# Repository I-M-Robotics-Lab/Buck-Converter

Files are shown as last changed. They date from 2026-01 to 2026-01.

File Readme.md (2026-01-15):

# A Simple Buck Converter Unit with ME3121

VIN Input: 5-40V

Output: 5V 1A; 3.3V 500mA

Dimension: 22 x 17 mm

This is a very compact Buck Converter Unit that turns a wide range of input voltage into the common 5V and 3.3V. It is cheap and have better performance than LM2596.

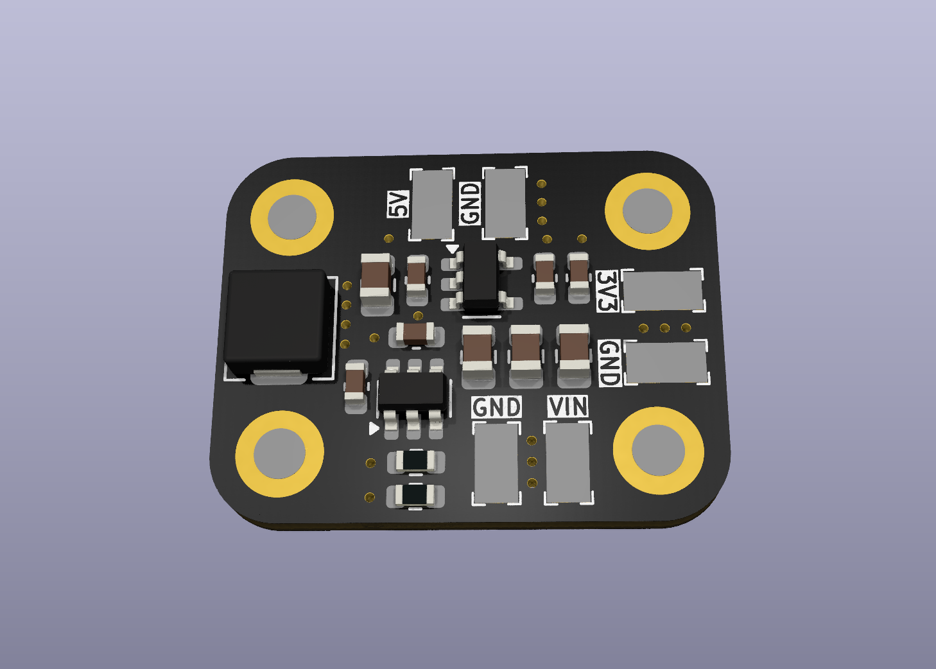
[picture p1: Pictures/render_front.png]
Rendered
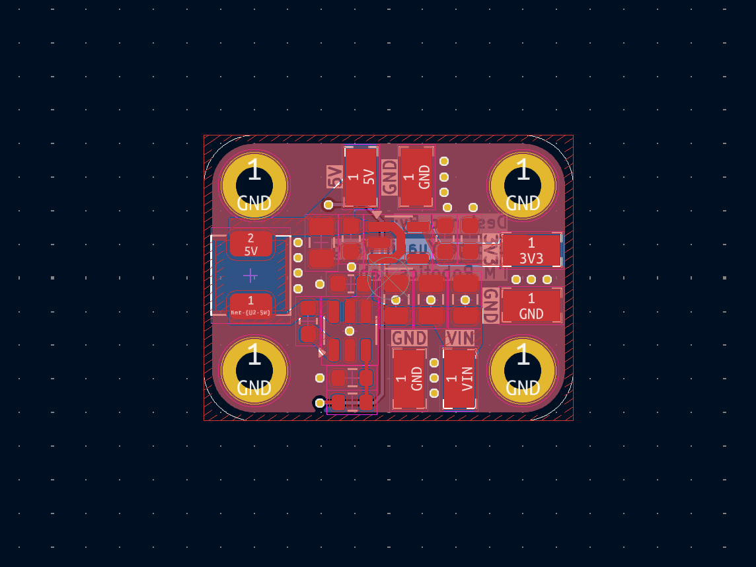
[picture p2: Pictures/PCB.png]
|  |  |
|---|---|

## Schematics

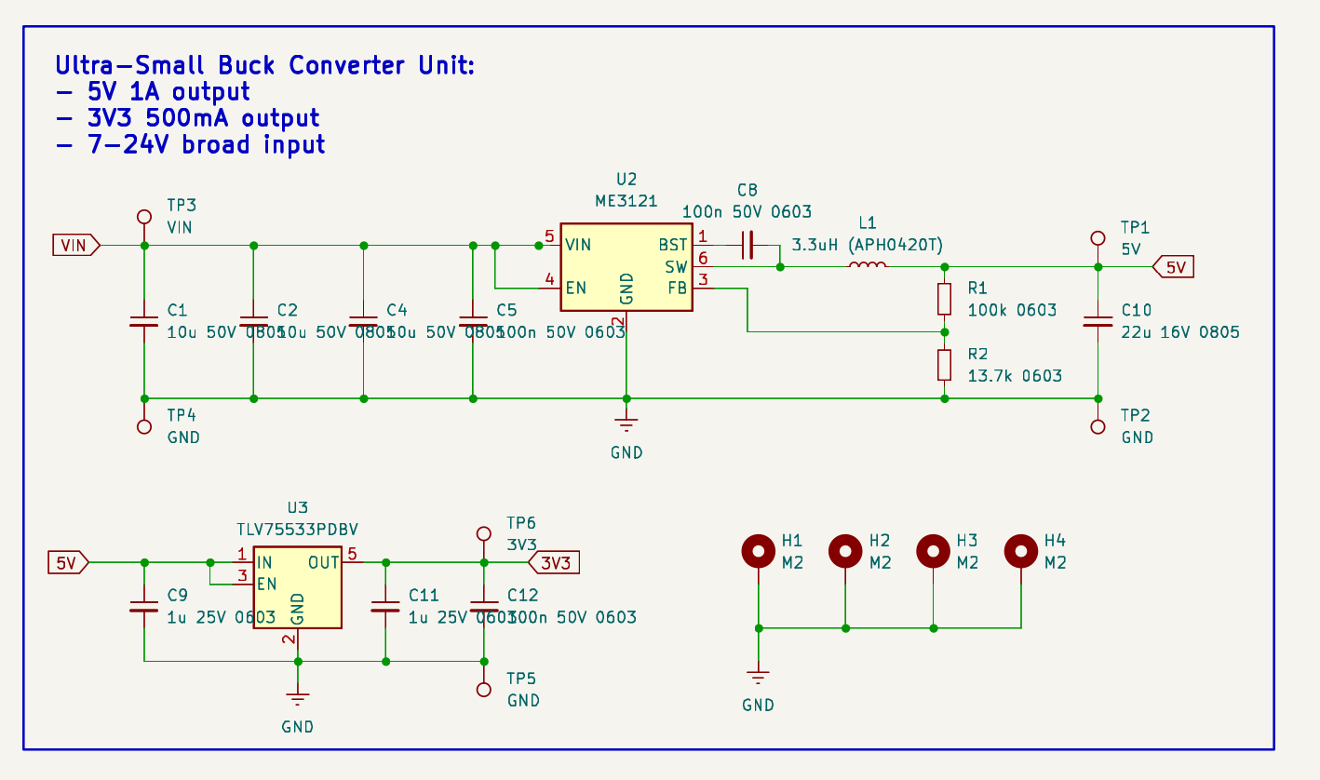
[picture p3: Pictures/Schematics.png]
Schematics


## Order / Manufacturing

Download the `Gerber.zip` file from release and submit it to [JLCPCB](https://cart.jlcpcb.com/quote?spm=jlcpcb.Public.2006), leave everything set as default. 

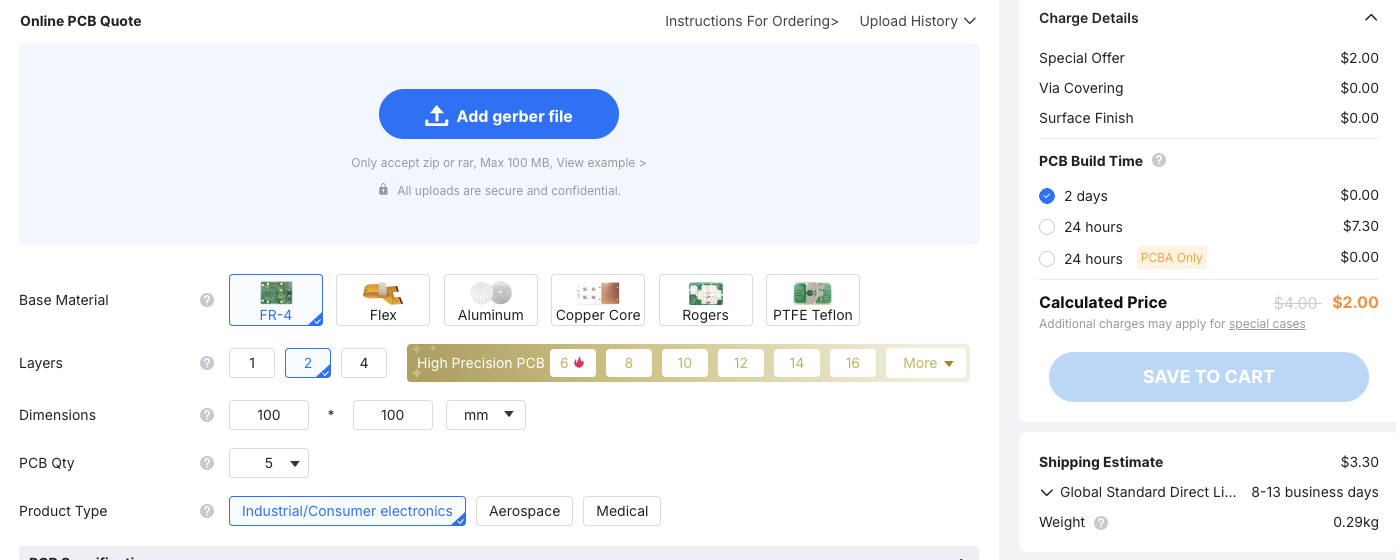
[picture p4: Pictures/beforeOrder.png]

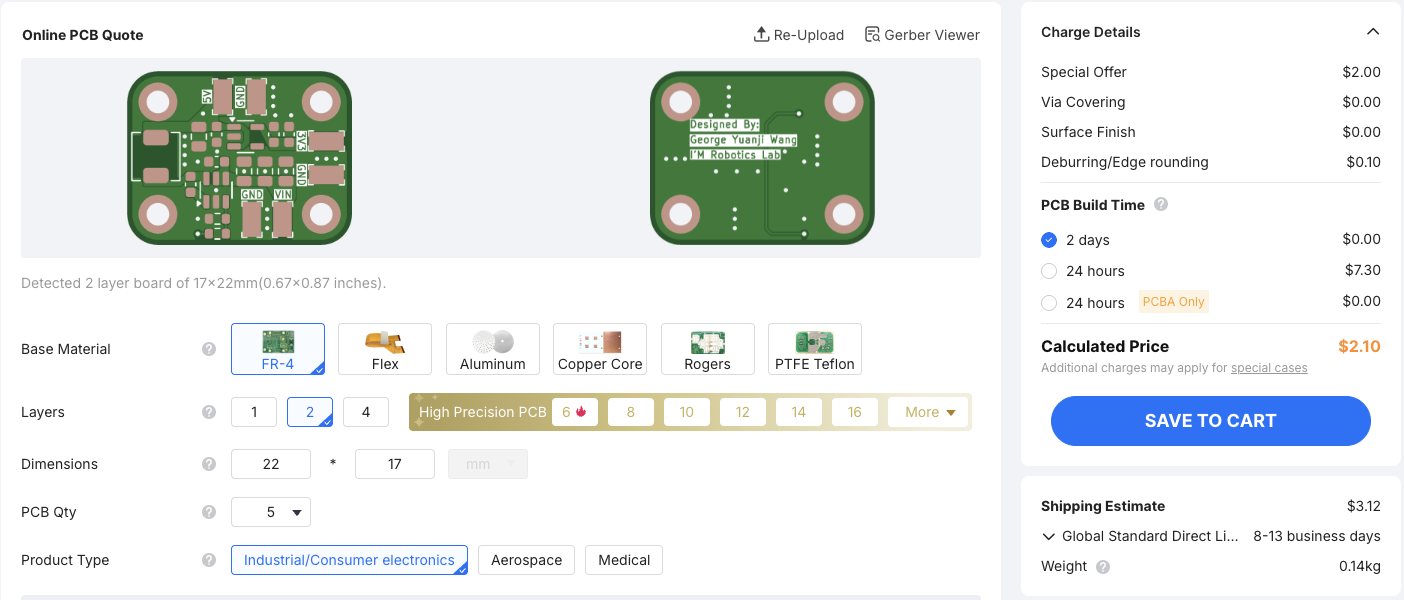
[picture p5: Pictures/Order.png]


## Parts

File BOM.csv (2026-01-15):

Reference | Value | Datasheet | Footprint | Qty | DNP
C1,C2,C4 | 10u 50V 0805 | ~ | Capacitor_SMD:C_0805_2012Metric | 3
C5,C8,C12 | 100n 50V 0603 | ~ | Capacitor_SMD:C_0603_1608Metric | 3
C9,C11 | 1u 25V 0603 | ~ | Capacitor_SMD:C_0603_1608Metric | 2
C10 | 22u 16V 0805 | ~ | Capacitor_SMD:C_0805_2012Metric | 1
L1 | 3.3uH (APH0420T) | https://lcsc.com/datasheet/lcsc_datasheet_2409302232_APV-APH0420T3R3M_C5349667.pdf | Inductor_SMD:L_APV_APH0420 | 1
R1 | 100k 0603 | ~ | Resistor_SMD:R_0603_1608Metric | 1
R2 | 13.7k 0603 | ~ | Resistor_SMD:R_0603_1608Metric | 1
U2 | ME3121 | https://lcsc.com/datasheet/lcsc_datasheet_2203311630_MICRONE-Nanjing-Micro-One-Elec-ME3121AM6G_C2932938.pdf | Package_TO_SOT_SMD:SOT-23-6 | 1
U3 | TLV75533PDBV | http://www.ti.com/lit/ds/symlink/tlv755p.pdf | Package_TO_SOT_SMD:SOT-23-5 | 1

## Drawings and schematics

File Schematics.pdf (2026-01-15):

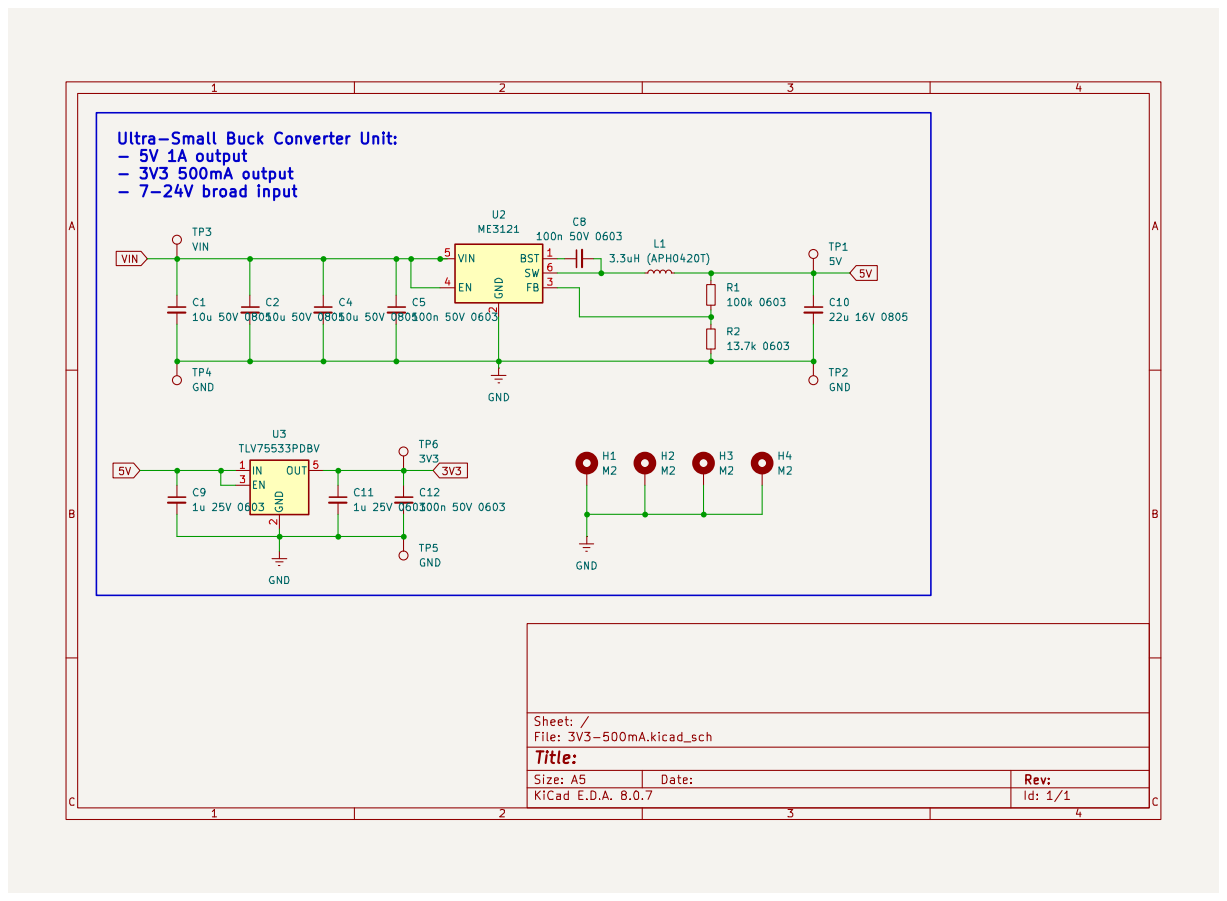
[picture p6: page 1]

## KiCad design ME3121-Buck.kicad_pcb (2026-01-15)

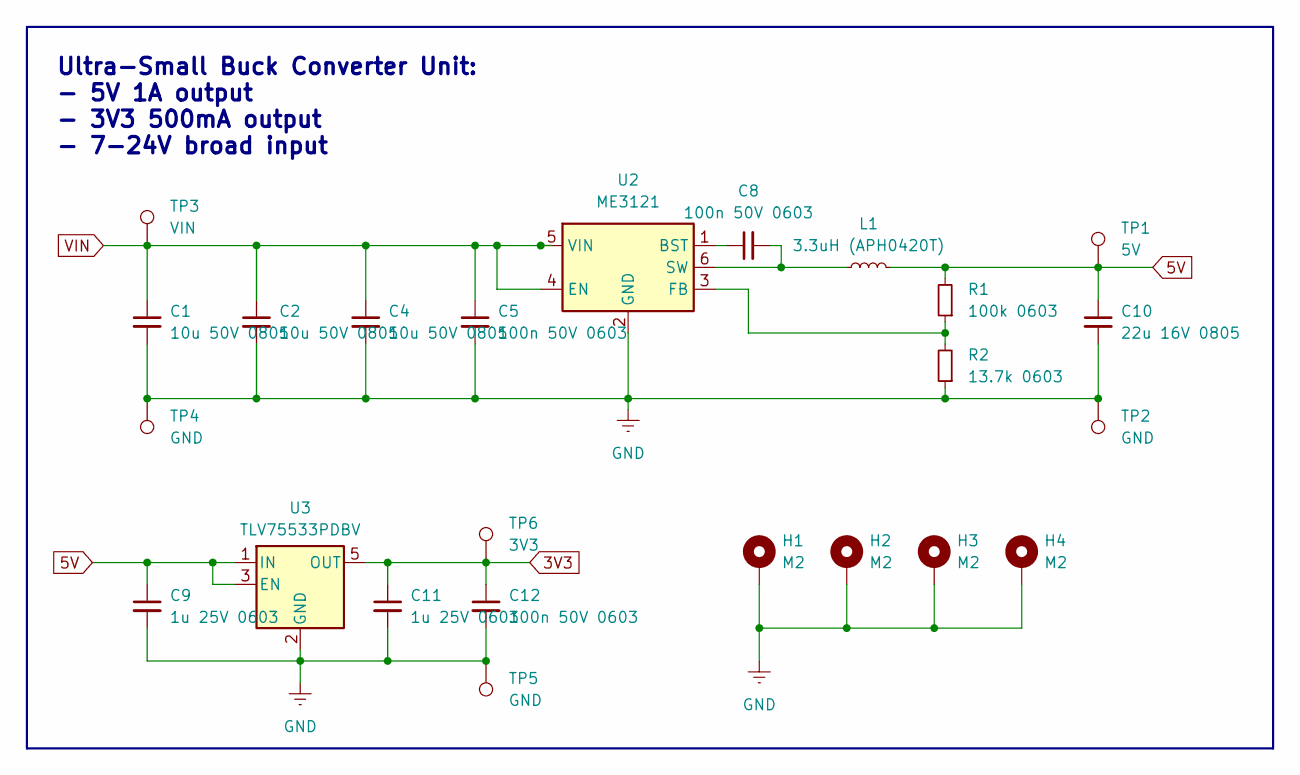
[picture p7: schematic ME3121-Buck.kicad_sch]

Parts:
C1, C2, C4: 10u 50V 0805; C_0805_2012Metric
C5, C8, C12: 100n 50V 0603; C_0603_1608Metric
C9, C11: 1u 25V 0603; C_0603_1608Metric
C10: 22u 16V 0805; C_0805_2012Metric
H1, H2, H3, H4: M2; MountingHole_2.2mm_M2_DIN965_Pad
L1: 3.3uH (APH0420T); L_APV_APH0420
R1: 100k 0603; R_0603_1608Metric
R2: 13.7k 0603; R_0603_1608Metric
TP1: 5V; PROBE_PAD_1206
TP2, TP4, TP5: GND; PROBE_PAD_1206
TP3: VIN; PROBE_PAD_1206
TP6: 3V3; PROBE_PAD_1206
U2: ME3121; SOT-23-6
U3: TLV75533PDBV; SOT-23-5

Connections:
3V3: C11.1, C12.1, TP6.1, U3.5 (OUT)
5V: C9.1, C10.1, L1.2, R1.2, TP1.1, U3.1 (IN), U3.3 (EN)
GND: C1.2, C2.2, C4.2, C5.2, C9.2, C10.2, C11.2, C12.2, H1.1, H2.1, H3.1, H4.1, R2.1, TP2.1, TP4.1, TP5.1, U2.2 (GND), U3.2 (GND)
unnamed: C8.1, U2.1 (BST)
unnamed: R1.1, R2.2, U2.3 (FB)
unnamed: C8.2, L1.1, U2.6 (SW)
VIN: C1.1, C2.1, C4.1, C5.1, TP3.1, U2.4 (EN), U2.5 (VIN)

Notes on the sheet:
Ultra-Small Buck Converter Unit: - 5V 1A output - 3V3 500mA output - 7-24V broad input

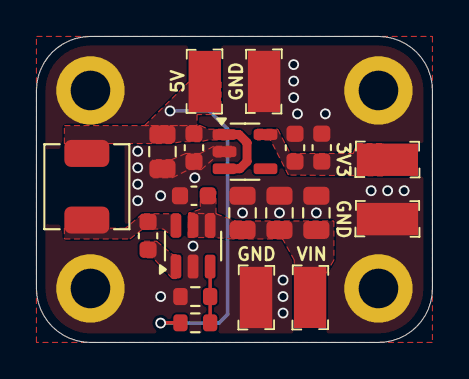
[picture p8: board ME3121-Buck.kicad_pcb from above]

Board: 2 copper layers, 22.0 x 17.0 mm, 24 parts (0 on the bottom side), 7 nets.
